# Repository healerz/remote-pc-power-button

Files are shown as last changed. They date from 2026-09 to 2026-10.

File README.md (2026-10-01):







# Remote PC Power Button

A wireless power button for a PC. A button on the desk switches the PC on and off, and its LED shows whether the PC is running. Inside the PC, a second unit closes the motherboard's power switch and senses the PC's power. The two units talk directly over ESP-NOW, so the button works without Home Assistant, the router or the PC's operating system; Home Assistant shows the PC's state and can control it, but is never in the path.

- [Overview](#overview)
- [How it works](#how-it-works)
- [Parts](#parts)
- [Build](#build)
- [Usage](#usage)
- [Known issues](#known-issues)
- [Previews](#previews)
- [Contributing](#contributing)
- [License](#license)
- [Contact](#contact)
- [Disclaimer](#disclaimer)

## Overview

- **Two units**, each an [Arduino Nano ESP32](https://docs.arduino.cc/hardware/nano-esp32/) running [ESPHome](https://esphome.io/): `pc-button-desk` on the desk, with the button; `pc-button-relay` inside the PC, with a relay across the power switch header.
- **The PC case's own power button keeps working**: the relay is wired in parallel to it.
- **Powered from 5 V standby**: the relay unit runs from a motherboard USB header that stays powered while the PC is off, which is exactly when the button is needed.
- **Printable cases** for both units, as `.3mf` with the print settings used, and as `.stl`.
- **Firmware** as one standalone ESPHome configuration per unit.

## How it works

```mermaid
flowchart LR
  HA["Home Assistant"]
  subgraph desk["On the desk"]
    BTN["Kolink button<br>switch and LED"]
    DESK["pc-button-desk<br>Nano ESP32"]
  end
  subgraph pc["PC"]
    RELAY["pc-button-relay<br>Nano ESP32"]
    USB["USB header<br>5VSB"]
    SATA["PSU<br>SATA 5 V"]
    PWR["motherboard<br>PWR_SW header"]
    CASE["case power button"]
  end
  HA <-. "WiFi, native API" .-> DESK
  BTN <-- "switch D2, LED D3" --> DESK
  DESK <-. "ESP-NOW" .-> RELAY
  USB -- "power, also while off" --> RELAY
  SATA -- "sense, via divider" --> RELAY
  RELAY -- "relay NO/COM" --> PWR
  CASE -- "in parallel" --> PWR

  classDef device fill:#e3f2fd,stroke:#1565c0,color:#0d47a1
  classDef part fill:#e8f5e9,stroke:#2e7d32,color:#1b5e20
  classDef module fill:#f3e5f5,stroke:#7b1fa2,color:#4a148c
  classDef connector fill:#e0f7fa,stroke:#00838f,color:#006064
  classDef external fill:#fff3e0,stroke:#ef6c00,color:#e65100
  classDef host fill:#eceff1,stroke:#546e7a,color:#263238
  classDef power fill:#ffebee,stroke:#c62828,color:#b71c1c
  classDef area fill:#fafafa,stroke:#bdbdbd,color:#424242
  classDef pin fill:#ffffff,stroke:#9e9e9e,color:#212121
  classDef passive fill:#ffffff,stroke:#616161,color:#212121
  class DESK,RELAY device
  class BTN,CASE part
  class HA external
  class PWR host
  class USB,SATA power
  class desk,pc area
```

A button press, from the desk to the PC and back:

```mermaid
%%{init: {"theme": "base", "themeCSS": ".actor[name^=device_]{fill:#e3f2fd!important;stroke:#1565c0!important}.actor[name^=device_]+text tspan{fill:#0d47a1!important}.actor[name^=part_]{fill:#e8f5e9!important;stroke:#2e7d32!important}.actor[name^=part_]+text tspan{fill:#1b5e20!important}.actor[name^=module_]{fill:#f3e5f5!important;stroke:#7b1fa2!important}.actor[name^=module_]+text tspan{fill:#4a148c!important}.actor[name^=connector_]{fill:#e0f7fa!important;stroke:#00838f!important}.actor[name^=connector_]+text tspan{fill:#006064!important}.actor[name^=external_]{fill:#fff3e0!important;stroke:#ef6c00!important}.actor[name^=external_]+text tspan{fill:#e65100!important}.actor[name^=host_]{fill:#eceff1!important;stroke:#546e7a!important}.actor[name^=host_]+text tspan{fill:#263238!important}.actor[name^=power_]{fill:#ffebee!important;stroke:#c62828!important}.actor[name^=power_]+text tspan{fill:#b71c1c!important}", "themeVariables": {"actorBkg": "#ffffff", "actorBorder": "#757575", "actorTextColor": "#212121", "actorLineColor": "#9e9e9e", "signalColor": "#212121", "signalTextColor": "#212121", "noteBkgColor": "#ffffff", "noteBorderColor": "#9e9e9e", "noteTextColor": "#212121", "labelBoxBkgColor": "#ffffff", "labelBoxBorderColor": "#212121", "labelTextColor": "#212121", "loopTextColor": "#212121"}}}%%
sequenceDiagram
  box rgb(250,250,250) On the desk
    participant part_button as Kolink button
    participant device_desk as pc-button-desk
  end
  box rgb(250,250,250) PC
    participant device_relay as pc-button-relay
    participant host_board as motherboard
  end
  participant external_ha as Home Assistant
  part_button->>device_desk: pressed
  device_desk->>device_relay: down
  loop every 50 ms while pressed
    device_desk->>device_relay: held
    device_relay->>host_board: relay closed across PWR_SW
  end
  part_button->>device_desk: released
  device_desk->>device_relay: up
  device_relay->>host_board: relay opens 300 ms after the last held
  host_board-->>device_relay: SATA 5 V comes on, D3 high
  device_relay->>device_desk: on, then every second
  device_desk->>external_ha: PC Power on
  device_desk->>part_button: LED on
```

- **The press is repeated, not sent once.** While the button is held, the desk unit sends `held` every 50 ms; the relay unit keeps the relay closed while these arrive and opens it 300 ms after the last one. A lost frame changes nothing, and the relay can never stick closed: an ATX board forces the PC off after about 4 s of a held power switch.
- **The PC's state is repeated too.** The relay unit reports `on` every 1 s while the PC is on, so the LED and Home Assistant heal from a lost frame by themselves.
- **The relay unit keeps its WiFi off.** Inside a PC case the WiFi signal is often weak, and a weak WiFi connection keeps scanning for a better access point. WiFi and ESP-NOW share one radio, so every scan takes it off the ESP-NOW channel for seconds: short taps got through, held presses did not. So the relay unit runs on ESP-NOW alone, and switches WiFi on only for updates, through the Satellite WiFi switch in Home Assistant.
- **It finds its way back by itself.** The relay unit remembers the WiFi channel of its last WiFi session and uses it for ESP-NOW. If the link is lost for about 5 minutes, for example because the router changed its channel, it switches WiFi on, learns the new channel, and returns to ESP-NOW on its own. No channel is configured anywhere.

## Parts

**Parts**

| Part | Qty | For | Details |
|---|---|---|---|
| Solder wire | 1 | project | electronics solder wire; for both units |
| [Double-sided tape](https://www.3m.com/3M/en_US/vhb-tapes-us/) | 1 | project | 3M; VHB acrylic foam tape, 5 m roll; mounts both units, the desk unit under the desk and the relay unit inside the PC case |
| [Arduino Nano ESP32 with headers](https://docs.arduino.cc/hardware/nano-esp32/) | 2 | pc-button-desk ×1, pc-button-relay ×1 | Arduino; pc-button-desk: the headers keep every pin reachable in the case, for jumper wires; pc-button-relay: the headers keep every pin reachable in the case, for jumper wires |
| External power button with cable | 1 | pc-button-desk | Kolink KL-EXPWR; push button with a blue LED, 1.65 m cable; not on the maker's website |
| Resistor, 200 Ω | 1 | pc-button-desk | 200 Ω; LED series resistor, in the patch cable between D3 (GPIO6) and the button's blue LED; limits the current to a few mA, so PWM sets the brightness |
| Jumper wires | 2 | pc-button-desk ×1, pc-button-relay ×1 | Dupont jumper wires, one set |
| USB-C cable | 1 | pc-button-desk | USB-C, to the charger, with a slim plug; a thick plug may not fit the opening of the case |
| USB charger | 1 | pc-button-desk | USB power supply, 5 V |
| Heat-set insert | 14 | pc-button-desk ×5, pc-button-relay ×9 | M3, brass |
| Screw | 14 | pc-button-desk ×5, pc-button-relay ×9 | M3 × 4 mm; pc-button-desk: 4 for the lid, 1 for the clamp that holds the board; pc-button-relay: 4 for the lid, 1 for the clamp that holds the board, 4 for the relay module |
| Heat-shrink tubing | 6 | pc-button-desk ×1, pc-button-relay ×5 | one piece per joint; pc-button-desk: over the joint where the LED resistor is soldered; pc-button-relay: 1 on the SATA power cable; 2 on the Y-split inside the case (power and ground to both the board and the relay module); 2 on the Y-split outside the case at the power switch header, so the PC case's own power button keeps working next to the relay |
| Case | 1 | pc-button-desk | printed: [pc-button-desk-case.3mf](models/pc-button-desk-case.3mf) |
| 1-channel relay module | 1 | pc-button-relay | Purecrea; 5 V, SRD-05VDC-SL-C relay, optocoupler input; trigger jumper on high level, contacts NO and COM used (see the README); the maker has no product page |
| JST XH connector, 5 pins | 1 | pc-button-relay | 2.5 mm pitch, socket in the case and plug on the harness, with crimp contacts; the harness connects the case to the custom-made cable (see photos 02 and 03) |
| SATA power cable | 1 | pc-button-relay | a spare SATA power cable of the PSU, modified; cut down to the 2 wires needed; the other wires cut and sealed with hot glue at the connector |
| Resistor, 10 kΩ | 1 | pc-button-relay | 10 kΩ; PSU sense divider, high side, soldered inline on the SATA power cable from its 5 V wire to the junction |
| Resistor, 20 kΩ | 1 | pc-button-relay | 20 kΩ; PSU sense divider, low side, from the junction to the spliced ground wire; the junction goes to D3 (GPIO6) at 5 V × 20/30 = 3.33 V, low enough in value to dominate the pin's 45 kΩ internal pull-down |
| Hot glue | 1 | pc-button-relay | glue sticks for the hot glue gun; seals the cut wires of the SATA power cable |
| Super glue | 1 | pc-button-relay | cyanoacrylate glue; holds the JST XH socket in the case, which has no stop against pulling it out |
| Case | 1 | pc-button-relay | printed: [pc-button-relay-case.3mf](models/pc-button-relay-case.3mf) |

**Tools**

| Tool | For | Details |
|---|---|---|
| 3D printer | project | for both cases |
| Soldering iron | project | for the wires, and to set the heat-set inserts |
| Wire stripper | project |  |
| [Soldering tips for heat-set inserts](https://www.ruthex.de/en/products/ruthex-lotspitzen-einschmelzhilfe-m2-m2-5-m3-m4-m5-m6-m8) (optional) | project | ruthex LOE-SET-012; set the inserts straight |
| Heat gun (optional) | project | to shrink the heat-shrink tubing; a soldering iron works too |
| Multimeter (optional) | project | to check the sense divider, about 3.0 V at the relay unit's D3 with the PC on and 0 V with it off |
| JST XH crimping tool | pc-button-relay |  |
| Hot glue gun | pc-button-relay | to seal the cut wires of the SATA power cable |

**Requires**

- A motherboard USB header that stays powered while the PC is off: 5VSB; the relay unit lives on it. The BIOS must keep it powered in the off state (ErP disabled, or USB power in S5 enabled), or the button does nothing while the PC is off
- A spare SATA power cable of this PSU, or a free SATA plug: for the relay unit's modified SATA power cable, which senses whether the PC is on. Modular PSU cables are specific to their PSU on the PSU end; a cable from another PSU can destroy hardware

## Build

### Printing

| Part | Files | Printer | Profile | Filament | Layer height | Infill | Walls | Supports |
|---|---|---|---|---|---|---|---|---|
| `pc-button-desk` case | [3mf](models/pc-button-desk-case.3mf), [stl](models/pc-button-desk-case.stl) | Bambu Lab X1 Carbon 0.4 nozzle | ESP_desk - 0.16mm High Quality @BBL X1C | Bambu PETG HF @BBL X1C | 0.16 mm | 20% | 4 | none |
| `pc-button-relay` case | [3mf](models/pc-button-relay-case.3mf), [stl](models/pc-button-relay-case.stl) | Bambu Lab X1 Carbon 0.4 nozzle | ESP_desk - 0.16mm High Quality @BBL X1C | Bambu PETG HF @BBL X1C | 0.16 mm | 20% | 4 | none |
| all: pc-remote-power-button-cases | [3mf](models/pc-remote-power-button-cases.3mf) | Bambu Lab X1 Carbon 0.4 nozzle | ESP_desk - 0.16mm High Quality @BBL X1C | Bambu PETG HF @BBL X1C | 0.16 mm | 20% | 4 | none |

Both cases are sized for the Nano ESP32 with headers, so all pins stay reachable for jumper wires. A Nano without headers fits as well; the case is then a bit bigger than needed.

Print both cases lying flat, in PETG. A case printed standing on its end broke under finger pressure: every wall then consists of layer boundaries.

### Wiring

#### Desk unit

The button's own leads go straight onto the board's header pins: the switch pair on D2 and the GND next to it, the LED through a 200 Ω resistor on D3 and back to the other GND.

```mermaid
%%{init: {"flowchart": {"subGraphTitleMargin": {"top": 0, "bottom": 8}, "rankSpacing": 60, "nodeSpacing": 55, "curve": "linear"}}}%%
flowchart LR
  subgraph CHARGER["USB charger, 5 V"]
    direction TB
    CHARGER_0["USB-C"]
  end
  subgraph CASE["Case"]
    direction LR
    subgraph NANO["Arduino Nano ESP32"]
      direction TB
      NANO_0["USB-C"]
      NANO_1["D2 (GPIO5)"]
      NANO_2["GND (by D2)"]
      NANO_3["GND (by VIN)"]
      NANO_4["D3 (GPIO6)"]
    end
    R3["200 Ω"]
  end
  subgraph BUTTON["Kolink power button"]
    direction TB
    BUTTON_0["SW A"]
    BUTTON_1["SW B"]
    BUTTON_2["LED-"]
    BUTTON_3["LED+"]
  end
  CHARGER_0 --- NANO_0
  NANO_1 --- BUTTON_0
  NANO_2 --- BUTTON_1
  NANO_3 --- BUTTON_2
  NANO_4 --- R3
  R3 --- BUTTON_3
  linkStyle 0 stroke:#212121,stroke-width:4px,marker-end:none
  linkStyle 1 stroke:#e0e0e0,stroke-width:4px,marker-end:none
  linkStyle 2 stroke:#00897b,stroke-width:4px,marker-end:none
  linkStyle 3 stroke:#212121,stroke-width:4px,marker-end:none
  linkStyle 4 stroke:#d32f2f,stroke-width:4px,marker-end:none
  linkStyle 5 stroke:#d32f2f,stroke-width:4px,marker-end:none

  classDef device fill:#e3f2fd,stroke:#1565c0,color:#0d47a1
  classDef part fill:#e8f5e9,stroke:#2e7d32,color:#1b5e20
  classDef module fill:#f3e5f5,stroke:#7b1fa2,color:#4a148c
  classDef connector fill:#e0f7fa,stroke:#00838f,color:#006064
  classDef external fill:#fff3e0,stroke:#ef6c00,color:#e65100
  classDef host fill:#eceff1,stroke:#546e7a,color:#263238
  classDef power fill:#ffebee,stroke:#c62828,color:#b71c1c
  classDef area fill:#fafafa,stroke:#bdbdbd,color:#424242
  classDef pin fill:#ffffff,stroke:#9e9e9e,color:#212121
  classDef passive fill:#ffffff,stroke:#616161,color:#212121
  class CHARGER power
  class NANO device
  class R3 passive
  class BUTTON part
  class CASE area
  class CHARGER_0,NANO_0,NANO_1,NANO_2,NANO_3,NANO_4,BUTTON_0,BUTTON_1,BUTTON_2,BUTTON_3 pin
```

#### Relay unit

The relay unit connects to the PC through one 5-pin JST XH connector in its case wall: 5VSB and GND from a motherboard USB header, the sense line, and the power switch pair.

```mermaid
%%{init: {"flowchart": {"subGraphTitleMargin": {"top": 0, "bottom": 8}, "rankSpacing": 60, "nodeSpacing": 55, "curve": "linear"}}}%%
flowchart LR
  subgraph SATA["SATA plug of the PSU"]
    direction TB
    SATA_0["+5V"]
    SATA_1["GND"]
  end
  R1["10 kΩ"]
  J(("Y-split"))
  R2["20 kΩ"]
  subgraph USB["USB header, 5VSB"]
    direction TB
    USB_0["5VSB"]
    USB_1["GND"]
  end
  subgraph PWRSW["PWR_SW header"]
    direction TB
    PWRSW_0["SW A"]
    PWRSW_1["SW B"]
  end
  subgraph BUTTON["PC case button"]
    direction TB
    BUTTON_0["SW A"]
    BUTTON_1["SW B"]
  end
  YA(("Y-split"))
  YB(("Y-split"))
  subgraph CASE["Case"]
    direction LR
    subgraph XH["XH, in the case wall"]
      direction TB
      XH_0["1 5VSB"]
      XH_1["2 GND"]
      XH_2["3 SENSE"]
      XH_3["4 SW A"]
      XH_4["5 SW B"]
    end
    S5V(("Y-split"))
    SGND(("Y-split"))
    subgraph NANO["Arduino Nano ESP32"]
      direction TB
      NANO_0["VBUS"]
      NANO_1["GND"]
      NANO_2["D2 (GPIO5)"]
      NANO_3["D3 (GPIO6)"]
    end
    subgraph RELAY["relay module"]
      direction TB
      RELAY_0["VCC"]
      RELAY_1["GND"]
      RELAY_2["COM"]
      RELAY_3["NO"]
      RELAY_4["IN"]
    end
  end
  SATA_0 --- R1
  R1 --- J
  SATA_1 --- R2
  R2 --- J
  J --- XH_2
  USB_0 --- XH_0
  USB_1 --- XH_1
  PWRSW_0 --- YA
  BUTTON_0 --- YA
  YA --- XH_3
  PWRSW_1 --- YB
  BUTTON_1 --- YB
  YB --- XH_4
  XH_0 --- S5V
  XH_1 --- SGND
  S5V --- RELAY_0
  SGND --- RELAY_1
  XH_3 --- RELAY_2
  XH_4 --- RELAY_3
  RELAY_4 --- NANO_2
  S5V --- NANO_0
  SGND --- NANO_1
  XH_2 --- NANO_3
  linkStyle 0 stroke:#d32f2f,stroke-width:4px,marker-end:none
  linkStyle 1 stroke:#7b1fa2,stroke-width:4px,marker-end:none
  linkStyle 2 stroke:#212121,stroke-width:4px,marker-end:none
  linkStyle 3 stroke:#7b1fa2,stroke-width:4px,marker-end:none
  linkStyle 4 stroke:#7b1fa2,stroke-width:4px,marker-end:none
  linkStyle 5 stroke:#d32f2f,stroke-width:4px,marker-end:none
  linkStyle 6 stroke:#212121,stroke-width:4px,marker-end:none
  linkStyle 7 stroke:#9e9e9e,stroke-width:4px,marker-end:none
  linkStyle 8 stroke:#9e9e9e,stroke-width:4px,marker-end:none
  linkStyle 9 stroke:#9e9e9e,stroke-width:4px,marker-end:none
  linkStyle 10 stroke:#fbc02d,stroke-width:4px,marker-end:none
  linkStyle 11 stroke:#fbc02d,stroke-width:4px,marker-end:none
  linkStyle 12 stroke:#fbc02d,stroke-width:4px,marker-end:none
  linkStyle 13 stroke:#d32f2f,stroke-width:4px,marker-end:none
  linkStyle 14 stroke:#212121,stroke-width:4px,marker-end:none
  linkStyle 15 stroke:#d32f2f,stroke-width:4px,marker-end:none
  linkStyle 16 stroke:#212121,stroke-width:4px,marker-end:none
  linkStyle 17 stroke:#9e9e9e,stroke-width:4px,marker-end:none
  linkStyle 18 stroke:#fbc02d,stroke-width:4px,marker-end:none
  linkStyle 19 stroke:#7b1fa2,stroke-width:4px,marker-end:none
  linkStyle 20 stroke:#d32f2f,stroke-width:4px,marker-end:none
  linkStyle 21 stroke:#212121,stroke-width:4px,marker-end:none
  linkStyle 22 stroke:#7b1fa2,stroke-width:4px,marker-end:none

  classDef device fill:#e3f2fd,stroke:#1565c0,color:#0d47a1
  classDef part fill:#e8f5e9,stroke:#2e7d32,color:#1b5e20
  classDef module fill:#f3e5f5,stroke:#7b1fa2,color:#4a148c
  classDef connector fill:#e0f7fa,stroke:#00838f,color:#006064
  classDef external fill:#fff3e0,stroke:#ef6c00,color:#e65100
  classDef host fill:#eceff1,stroke:#546e7a,color:#263238
  classDef power fill:#ffebee,stroke:#c62828,color:#b71c1c
  classDef area fill:#fafafa,stroke:#bdbdbd,color:#424242
  classDef pin fill:#ffffff,stroke:#9e9e9e,color:#212121
  classDef passive fill:#ffffff,stroke:#616161,color:#212121
  class SATA,USB power
  class R1,J,R2,YA,YB,S5V,SGND passive
  class PWRSW host
  class BUTTON part
  class XH connector
  class NANO device
  class RELAY module
  class CASE area
  class SATA_0,SATA_1,USB_0,USB_1,PWRSW_0,PWRSW_1,BUTTON_0,BUTTON_1,XH_0,XH_1,XH_2,XH_3,XH_4,NANO_0,NANO_1,NANO_2,NANO_3,RELAY_0,RELAY_1,RELAY_2,RELAY_3,RELAY_4 pin
```

- **Relay module:** set its trigger jumper to high level, and use the contacts NO and COM. On low level, the relay would close during every boot and press the PC's power switch; on NC the switch would be held closed.
- **Power switch:** two Y-splits put the relay in parallel to the PC case's own button, on the motherboard's power switch header.
- **Power sense:** a 10 kΩ / 20 kΩ divider on the 5 V wire of a spare SATA power cable of the PSU gives about 3.3 V at D3 while the PC is on. Use a cable of this PSU only: modular PSU cables are specific to their PSU, and a cable from another PSU can destroy hardware.
- **Power supply:** 5VSB from a USB header that stays powered while the PC is off (BIOS: ErP disabled, or USB power in S5 enabled). VBUS is wired straight to the board's USB-C port, so unplug the harness before connecting a USB-C cable to the board.

### Assembly

- **Both cases:** the Nano ESP32 goes in USB-C end first, and a printed clamp, screwed on at the antenna end, holds it down. All header pins stay reachable, so the wiring plugs on with jumper wires. The lid is held by 4 M3 screws in heat-set inserts.
- **Desk unit:** shaking the case a little seats the board. The opening for the USB-C cable fits a slim plug. The button's cable is held by the pressure of the lid, which also relieves the strain on its leads.
- **Relay unit:** the relay module is held by 4 screws. The XH socket sits in the case wall; the case has a stop against pushing it in but none against pulling it out, so glue it in (cyanoacrylate).
- **Mounting:** double-sided tape holds both units, the desk unit under the desk and the relay unit inside the PC case.

### Flashing

The configurations are in [`esphome/`](esphome/), one standalone file per unit, for the [ESPHome](https://esphome.io/) dashboard, the Home Assistant add-on or the command line. They need ESPHome 2026.9.0 or newer, and Home Assistant: its Satellite WiFi switch is the only way to switch the relay unit's WiFi off after the first flash, and on for updates.

1. **Secrets:** copy [`esphome/secrets.example.yaml`](esphome/secrets.example.yaml) to `secrets.yaml` next to the configurations and fill in your WiFi. Give each unit its own API encryption key, for example from `openssl rand -base64 32`.
2. **First flash, over USB:** flash both units once. Each one logs its MAC address at boot (`Local MAC` in the WiFi section of the log).
3. **MACs:** each unit sends to the other one's MAC. Put the relay unit's MAC into the desk unit's configuration (`pc_button_relay_mac` in its `substitutions`), and the desk unit's MAC into the relay unit's (`pc_button_desk_mac`).
4. **Second flash:** the relay unit first, then the desk unit. Both units have to run the same release: the desk unit repeats its WiFi commands, which an older relay unit would answer by rebooting over and over.
5. **Home Assistant:** add the desk unit through the ESPHome integration, with its API key. The relay unit has no entities and needs no integration.
6. **WiFi off:** a newly flashed relay unit starts with WiFi on, so it can learn the channel. Once it has joined your WiFi, switch Satellite WiFi off in Home Assistant.

## Usage

- **Button:** press it to switch the PC on or off, as with the case's own button. Holding it for about 4 s forces the PC off.
- **LED:** lit while the PC is on.
- **Home Assistant** (desk unit):
  - *PC Power*: whether the PC is on.
  - *Satellite Link*: whether the desk unit hears the relay unit.
  - *Satellite WiFi*: the relay unit's WiFi. Switch it on to update the relay unit over the air, and off afterwards. The switch shows the relay unit's own report, not just the command.
- **Updating the relay unit:** switch Satellite WiFi on, wait until the relay unit is online, flash it, and switch Satellite WiFi off again. WiFi that cannot connect within 5 min switches itself off again.

## Known issues

- Both units must be flashed together, relay unit first: the desk unit's repeated WiFi commands would keep an older relay unit rebooting.
- WiFi reception inside a PC case can be too weak for the relay unit to hold a connection, so an OTA update may need the case opened or several attempts; the button itself does not depend on WiFi.
- While the relay unit is on WiFi, the ESP-NOW link is less reliable: WiFi scans take the shared radio off the channel.
- ESP-NOW frames are not authenticated: the units only accept frames from each other's MAC address, which a sender in radio range could imitate.
- Recovering the desk unit from a broken configuration needs USB, since it has no fallback access point.

## Previews

### Desk unit

The printed case body with threaded inserts, the lid and the small plate

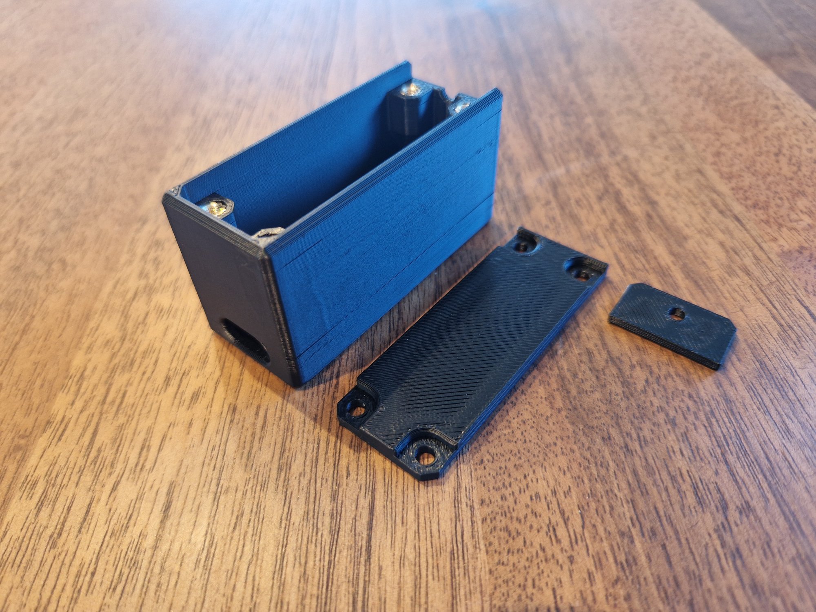
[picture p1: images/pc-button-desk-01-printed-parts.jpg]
the printed case body with threaded inserts, the lid and the small plate


The Nano ESP32 in the open case, wired to the button cable

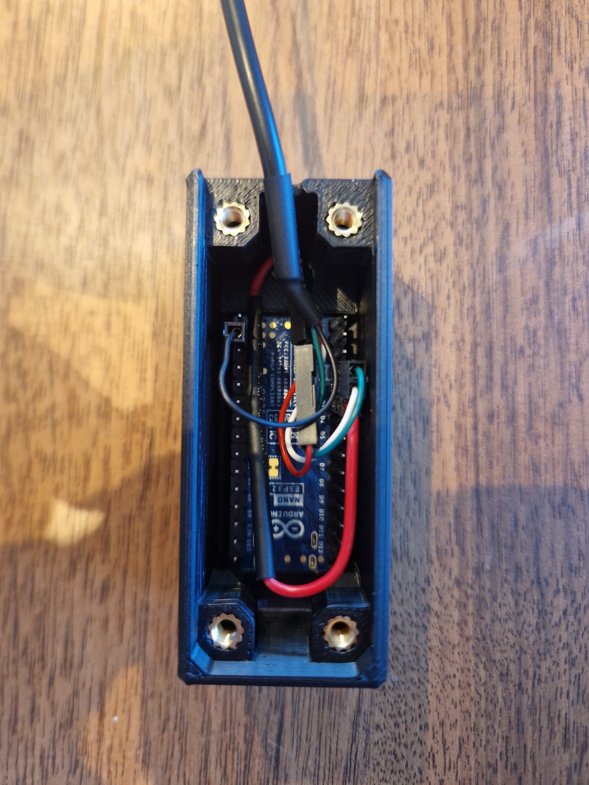
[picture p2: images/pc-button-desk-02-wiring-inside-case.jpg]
the Nano ESP32 in the open case, wired to the button cable


The closed case next to the key-switch power button

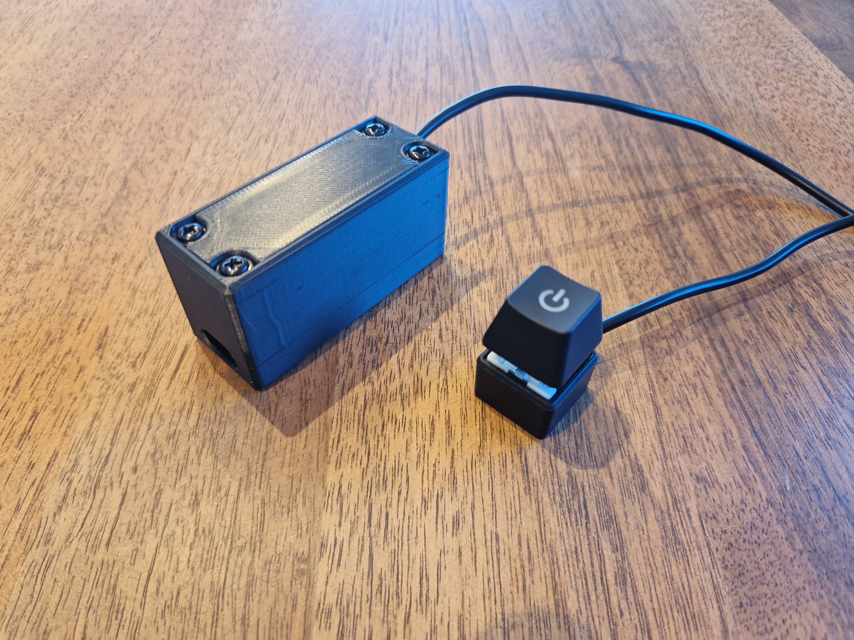
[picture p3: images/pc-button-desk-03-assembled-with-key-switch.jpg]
the closed case next to the key-switch power button


Mounted under the desk, the button lit blue while the PC is on

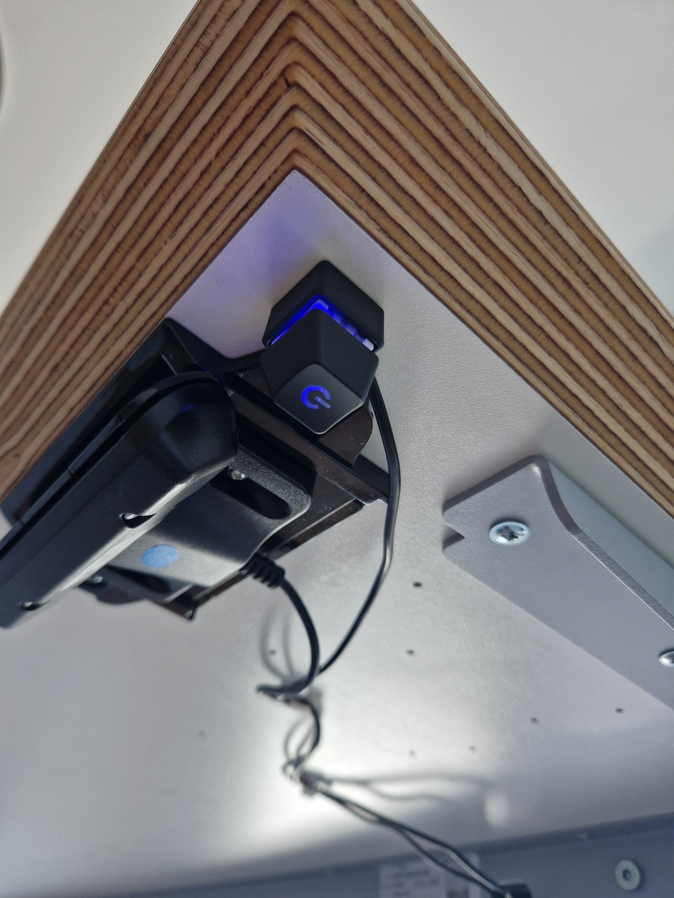
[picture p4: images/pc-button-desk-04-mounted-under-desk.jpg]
mounted under the desk, the button lit blue while the PC is on


Section view of the case design in Fusion: the lid, the screw channels and the slot for the board

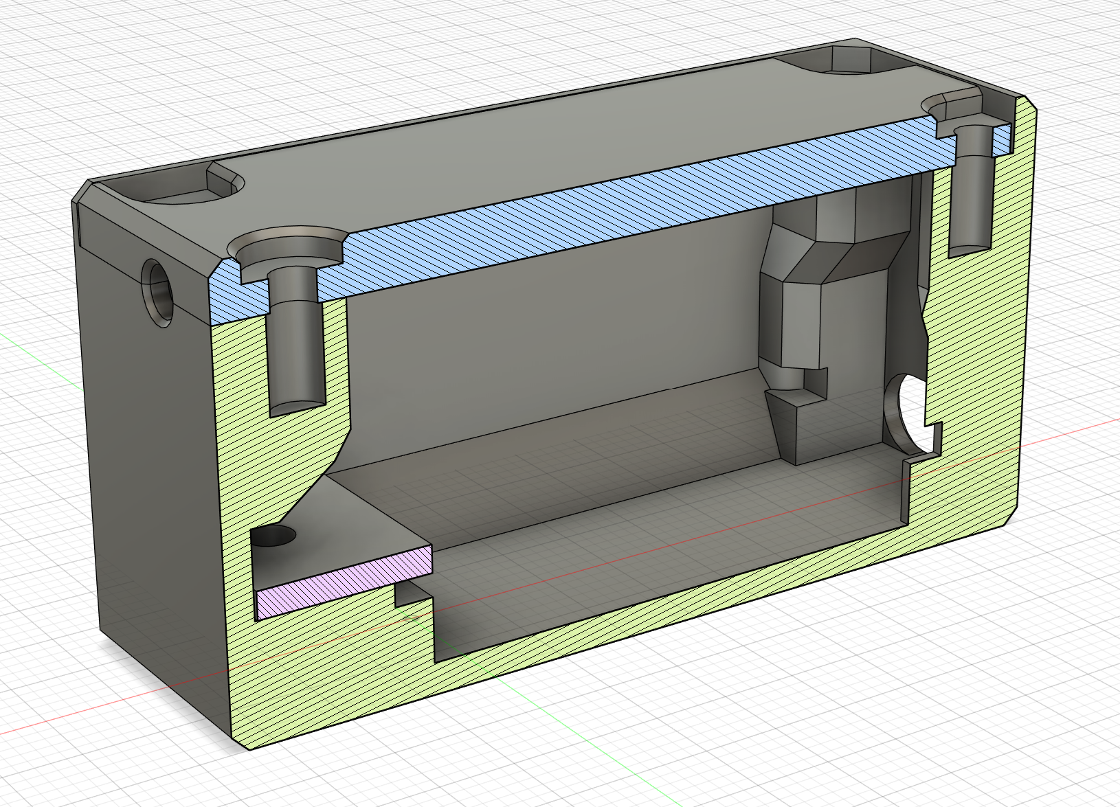
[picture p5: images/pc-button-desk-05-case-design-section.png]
section view of the case design in Fusion: the lid, the screw channels and the slot for the board


### Relay unit

The printed case body with threaded inserts, the lid and the small plate

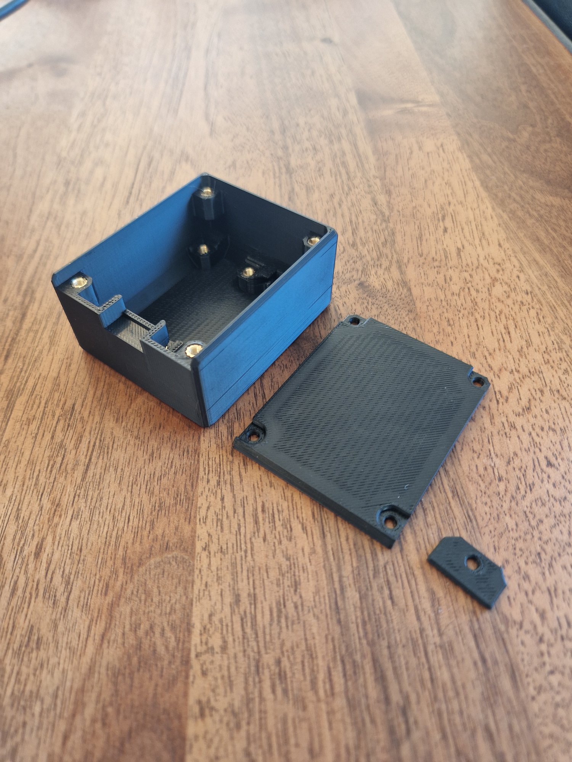
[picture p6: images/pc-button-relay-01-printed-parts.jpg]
the printed case body with threaded inserts, the lid and the small plate


The relay module, the Nano ESP32 and the 5-pin connector in the open case

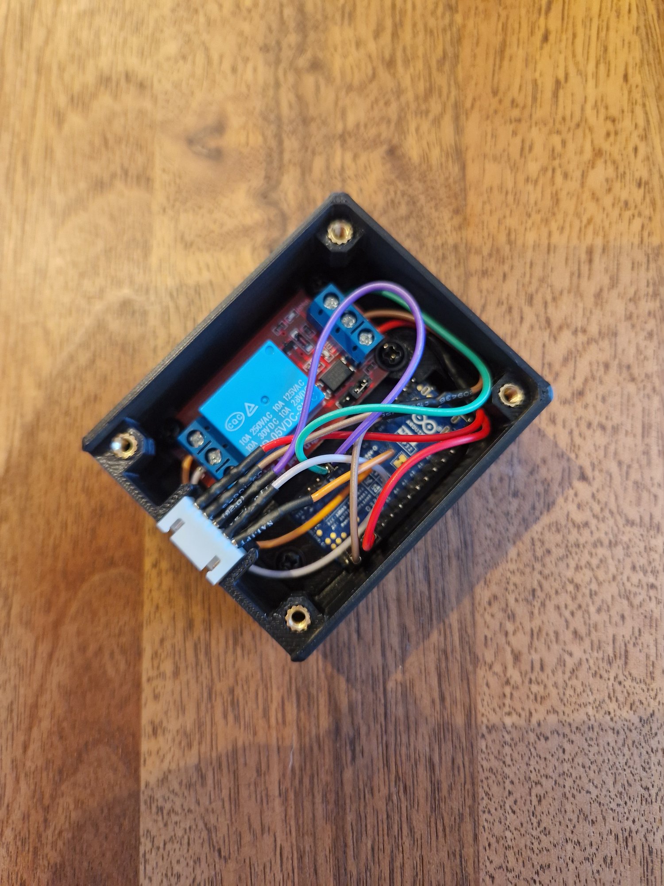
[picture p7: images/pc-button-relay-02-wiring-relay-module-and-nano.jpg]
the relay module, the Nano ESP32 and the 5-pin connector in the open case


The closed case with the 5-pin harness to the motherboard headers

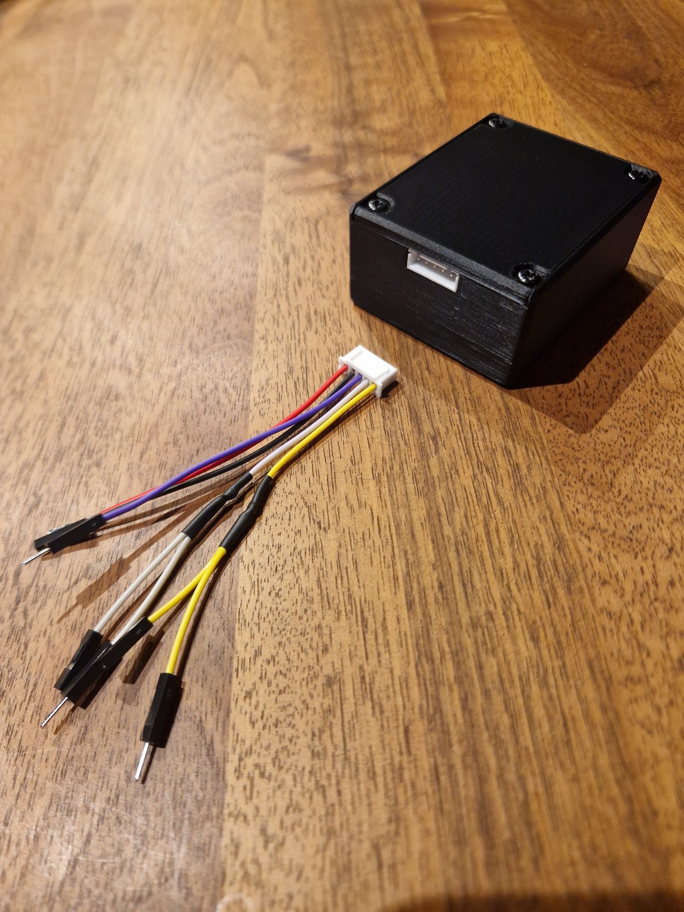
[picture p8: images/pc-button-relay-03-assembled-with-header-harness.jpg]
the closed case with the 5-pin harness to the motherboard headers


Installed inside the PC case, below the graphics card

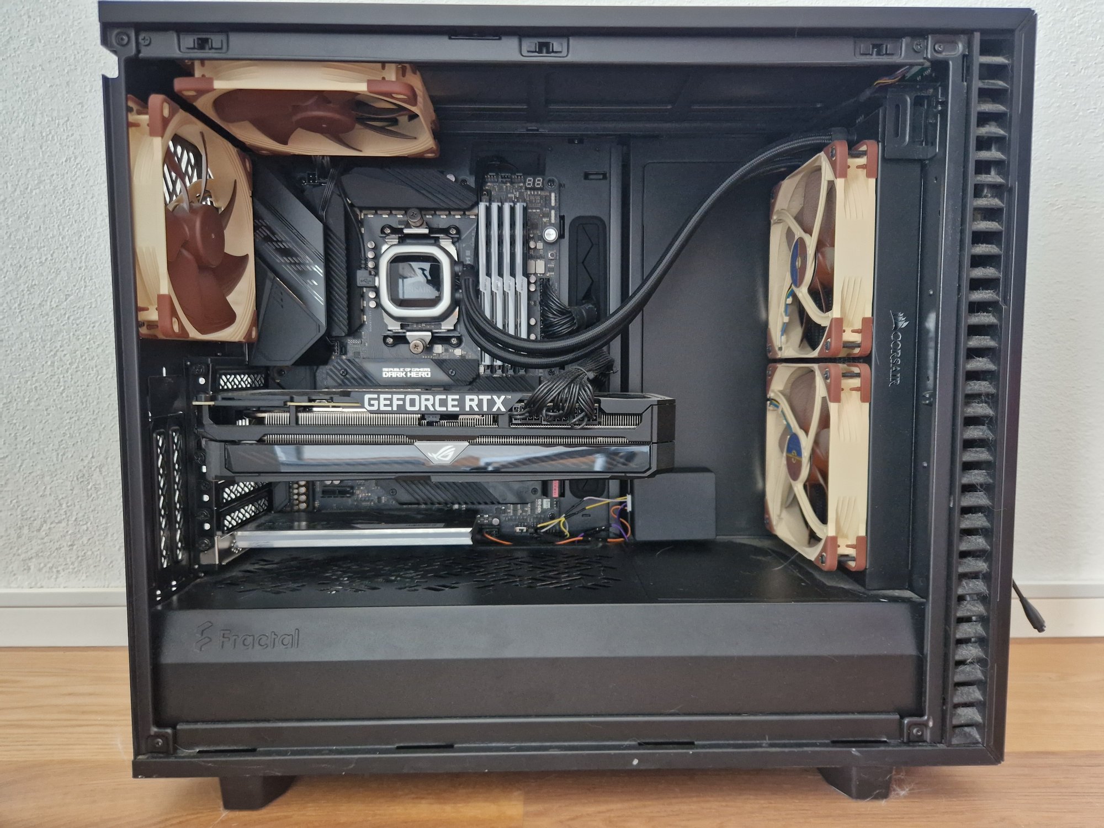
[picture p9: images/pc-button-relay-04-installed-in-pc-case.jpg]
installed inside the PC case, below the graphics card


Section view of the case design in Fusion: the lid and the mounts for the relay module and the board

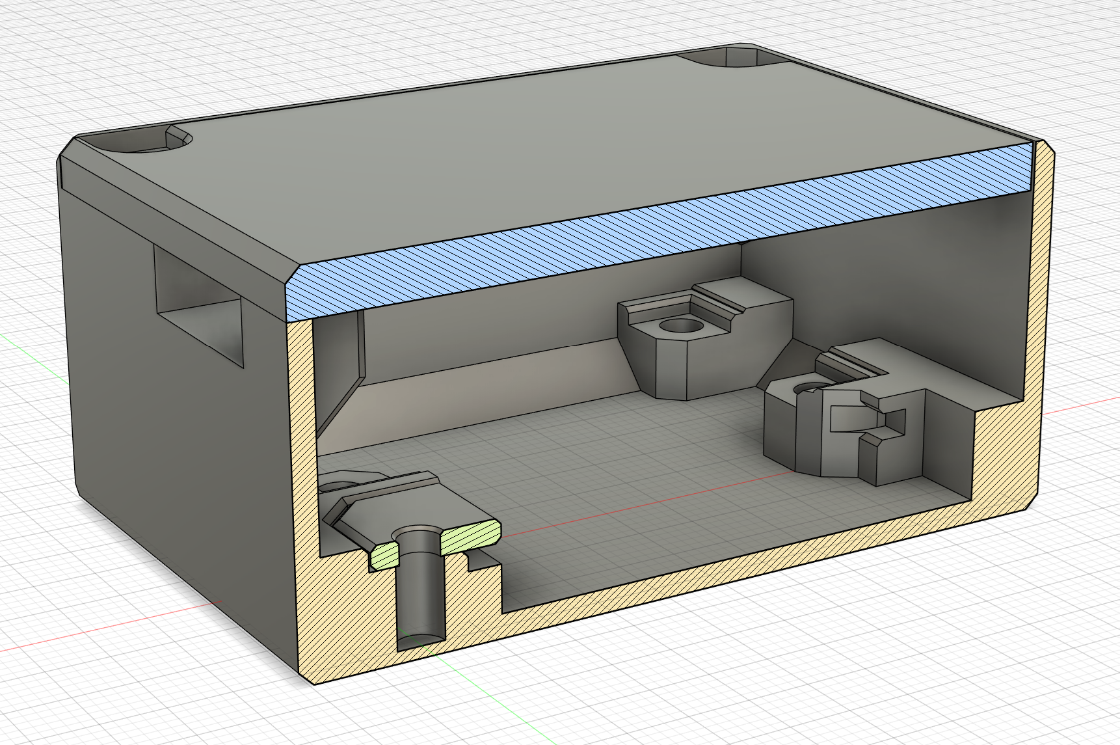
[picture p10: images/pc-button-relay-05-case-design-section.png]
section view of the case design in Fusion: the lid and the mounts for the relay module and the board


## Contributing

Contributions are welcome! You can help by:
- Suggesting improvements to the design or the firmware
- Testing it with other boards, cases or PCs, and sharing the results
- Improving the documentation

To contribute, open an issue or a pull request.

## License

This project is licensed under the [Creative Commons Attribution-NonCommercial-ShareAlike 4.0 International (CC BY-NC-SA 4.0)](https://creativecommons.org/licenses/by-nc-sa/4.0/) license, the configurations included.

You are free to:
- Share: copy and redistribute the material in any medium or format
- Adapt: remix, transform, and build upon the material

Under the following terms:
- Attribution: you must credit the creator.
- NonCommercial: you may not use the material for commercial purposes.
- ShareAlike: you must distribute your contributions under the same license.

## Contact

Questions, feedback, or suggestions? Open an [issue](../../issues).

## Disclaimer

This project is not affiliated with Kolink, Arduino, Espressif, ESPHome or Home Assistant. Working inside a PC and modifying PSU cables is at your own risk: disconnect the PC from mains power before opening it, and check the wiring before powering it again.

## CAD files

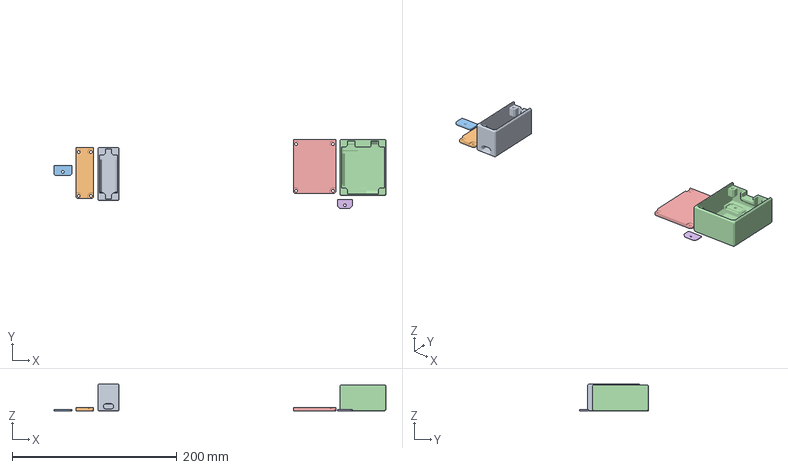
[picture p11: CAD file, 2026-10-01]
models/pc-remote-power-button-cases.3mf
403.1 x 83.8 x 32.6 mm

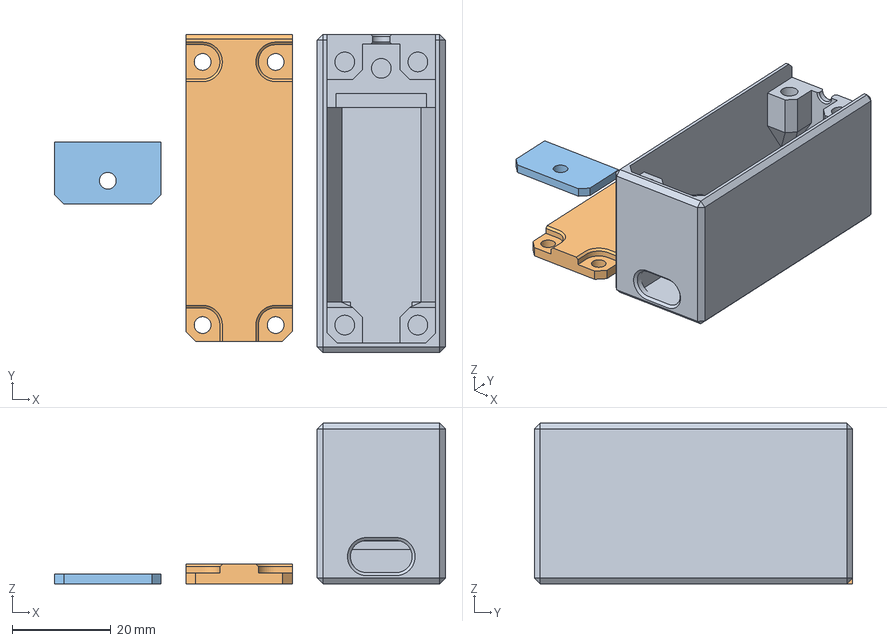
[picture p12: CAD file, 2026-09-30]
models/pc-button-desk-case.3mf
79.2 x 64.5 x 32.6 mm

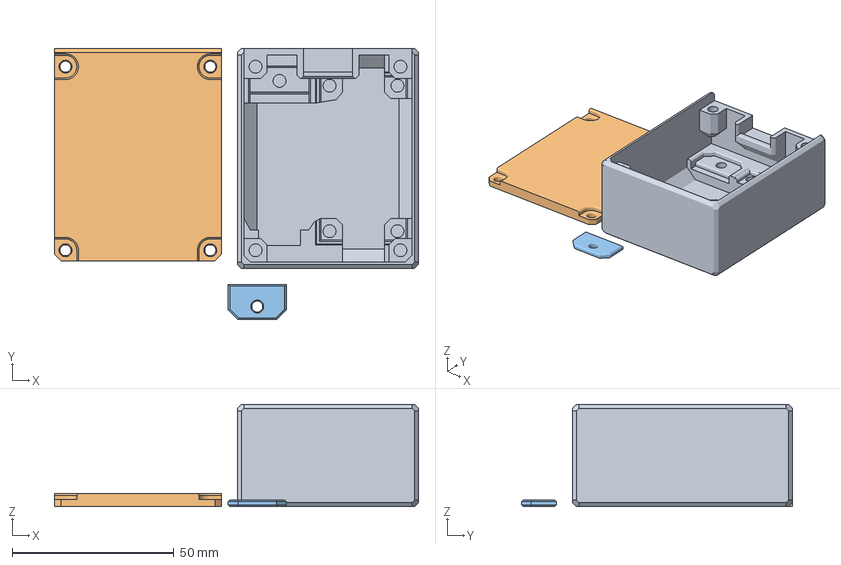
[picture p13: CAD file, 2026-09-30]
models/pc-button-relay-case.3mf
112.6 x 83.8 x 31.6 mm

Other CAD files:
models/pc-button-desk-case.stl
models/pc-button-relay-case.stl

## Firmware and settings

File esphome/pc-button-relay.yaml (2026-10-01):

# remote-pc-power-button v2.0.4: pc-button-relay. See the README for the secrets and the MACs to fill in.

# Board: Arduino Nano ESP32, inside the PC; remote I/O of pc-button-desk
# Actuator: relay on PWR_SW header | Sensor: PSU 5V divider
# Powered from USB header 5VSB, alive while the PC is off; do not move to a switched rail.
#
# WiFi is off by default so the radio never leaves the AP's channel to scan.
# Turn it on via the desk unit's "Satellite WiFi" switch when OTA is needed.
# Rescue: rescue_failures consecutive failed reports while WiFi is off → enable WiFi and reboot.
# ESP-NOW with WiFi off uses the channel of the last WiFi session, saved on
# connect. Until a channel has been saved (a new board), it always starts with
# WiFi on: without a known channel ESP-NOW cannot work, so there is no guessing.
# A router channel change heals itself: the rescue brings WiFi back on the new
# channel, and after rescue_return_reports reports delivered on WiFi the unit switches WiFi off
# again and carries the saved channel over to ESP-NOW. Only a rescue returns
# by itself; WiFi switched on by wifi_on stays on until wifi_off, unless it has
# not connected wifi_connect_timeout after boot: then the unit returns to WiFi off.
#
# No fallback access point and no captive portal: they would contradict WiFi
# being off by default.

substitutions:
  name: pc-button-relay
  project: remote-pc-power-button
  pc_button_desk_mac: "02:00:00:00:00:21"  # MAC of that unit, from its boot log (see the README)
  held_timeout: 300ms # relay unit opens the relay this long after the last held
  state_interval: 1s # relay unit repeats on this often while the PC is on
  report_interval: 30s # relay unit reports its WiFi state this often
  rescue_failures: "10"        # failed reports in a row, with WiFi off, before the rescue: 5 min at report_interval
  rescue_return_reports: "3"   # reports delivered on WiFi after a rescue before WiFi goes off again
  wifi_connect_timeout: 5min   # WiFi that has not connected this long after boot falls back to off
  sense_debounce: 100ms        # the PC power sense must hold its new level this long to count

esphome:
  project:
    name: ${project}.${name}
    version: v2.0.4
  name: ${name}
  friendly_name: PC Button Relay
  on_boot:
    - priority: 250                 # after logger and core components
      then:
        - lambda: |-
            ESP_LOGI("sat", "boot: boot_wifi_enabled=%s",
                     id(boot_wifi_enabled) ? "true" : "false");
        - if:
            condition:
              lambda: 'return id(boot_wifi_enabled) || id(espnow_channel) == 0;'
            then:
              - lambda: |-
                  ESP_LOGI("sat", "boot: enabling wifi%s",
                           id(espnow_channel) == 0 ? " (no espnow channel saved yet)" : "");
              - wifi.enable:
              - script.execute: wifi_connect_watchdog
            else:
              - espnow.set_channel: !lambda 'return id(espnow_channel);'
              - lambda: 'ESP_LOGI("sat", "boot: wifi stays off, channel set to %u", id(espnow_channel));'
    - priority: -100                # after everything is up
      then:
        - script.execute: report_wifi_state

esp32:
  variant: esp32s3
  flash_size: 16MB
  framework:
    type: esp-idf

globals:
  - id: boot_wifi_enabled
    type: bool
    restore_value: true
    initial_value: 'true'           # fresh flash comes up reachable

  - id: espnow_channel              # channel of the last WiFi session
    type: uint8_t
    restore_value: true
    initial_value: '0'              # 0: none saved yet, so WiFi starts on

  - id: wifi_by_rescue              # WiFi is on because of a rescue, not wifi_on
    type: bool
    restore_value: true
    initial_value: 'false'

  - id: rescue_reports              # reports delivered on WiFi since a rescue
    type: int
    restore_value: false
    initial_value: '0'

  - id: rescue_return               # reports it takes to switch WiFi off again
    type: int
    restore_value: false
    initial_value: '${rescue_return_reports}'

  - id: send_failures               # consecutive failed reports
    type: int
    restore_value: false
    initial_value: '0'

  - id: fail_threshold              # rescue_failures reports at report_interval
    type: int
    restore_value: false
    initial_value: '${rescue_failures}'

api:                                # kept for OTA/logs only — no entities
  encryption:
    key: !secret pc_button_relay_api_key
  reboot_timeout: 0s                # relay unit runs HA-less by design


ota:
  - platform: esphome
    encryption:                     # inherits the api key

safe_mode:                          # after repeated failed boots: WiFi on, so an OTA update can recover it
  on_safe_mode:
    - wifi.enable:
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

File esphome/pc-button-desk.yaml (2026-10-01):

# remote-pc-power-button v2.0.4: pc-button-desk. See the README for the secrets and the MACs to fill in.

# Desk unit: the physical power button and status LED, on WiFi and in Home
# Assistant. Talks to pc-button-relay inside the PC over ESP-NOW.
# Board: Arduino Nano ESP32.
#
# No fallback access point: it would open on a channel of its
# own when the router is away, and take the radio off the ESP-NOW channel the
# relay unit uses; the button would stop working exactly when it should not
# depend on the router. Recovery is over USB, next to the desk.

substitutions:
  name: pc-button-desk
  project: remote-pc-power-button
  pc_button_relay_mac: "02:00:00:00:00:22"  # MAC of that unit, from its boot log (see the README)
  held_interval: 50ms # desk unit repeats held this often while the button is pressed
  led_timeout: 4s # desk unit takes the PC as off after this long without on
  link_timeout: 90s # desk unit takes the link as lost after this long without any frame
  wifi_request_interval: 1s    # a WiFi request is repeated this often until the relay unit reports it
  wifi_request_limit: "300"    # requests before giving up: 5 min at one per second

esphome:
  project:
    name: ${project}.${name}
    version: v2.0.4
  name: ${name}
  friendly_name: PC Button Desk
  on_boot:
    - script.execute: led_state_watchdog

esp32:
  variant: esp32s3
  flash_size: 16MB
  framework:
    type: esp-idf

globals:
  - id: wifi_request              # relay unit WiFi asked for: 0 none, 1 on, 2 off
    type: int
    restore_value: false
    initial_value: '0'

  - id: wifi_request_sends        # repeats of the current request
    type: int
    restore_value: false
    initial_value: '0'

  - id: sat_wifi_known            # relay unit WiFi as last reported: -1 unknown, 0 off, 1 on
    type: int
    restore_value: false
    initial_value: '-1'

logger:
  logs:
    script: INFO                    # the two watchdogs re-arm every second

api:
  encryption:
    key: !secret pc_button_desk_api_key
  reboot_timeout: 0s                # the button works without Home Assistant: no reboot when it is away

ota:
  - platform: esphome
    encryption:                     # inherits the api key

safe_mode:                          # after repeated failed boots, wait for an OTA update

wifi:
  ssid: !secret wifi_ssid
  password: !secret wifi_password
  power_save_mode: none
  reboot_timeout: 0s                # nor when the router is away

# ── ESP-NOW link to the relay unit ─────────────────────────────
# → down / held / up / wifi_on / wifi_off
# ← on / off                             (PC power)
# ← sat_wifi_enabled / sat_wifi_disabled (relay unit WiFi component state)
espnow:
  peers:
    - ${pc_button_relay_mac}
  on_receive:
    - lambda: 'id(sat_link).publish_state(true);'   # any frame proves the link
    - script.execute: link_watchdog
    - if:
        condition:
          lambda: 'return size == 2 && memcmp(data, "on", 2) == 0;'
        then:
          - light.turn_on:
              id: status_led
              brightness: 60%
          - binary_sensor.template.publish:
              id: pc_power_remote
              state: ON
          - script.execute: led_state_watchdog
    - if:
        condition:
          lambda: 'return size == 3 && memcmp(data, "off", 3) == 0;'
        then:
          - script.stop: led_state_watchdog
          - light.turn_off: status_led
          - binary_sensor.template.publish:
              id: pc_power_remote
              state: OFF
    - if:
        condition:
          lambda: 'return size == 16 && memcmp(data, "sat_wifi_enabled", 16) == 0;'
        then:
          - lambda: |-
              id(sat_wifi_sw).publish_state(true);
              if (id(sat_wifi_known) == 0 && id(wifi_request) != 1)   // a rescue
                ESP_LOGW("sat", "relay unit switched its WiFi on by itself");
              id(sat_wifi_known) = 1;
              if (id(wifi_request) == 1) id(wifi_request) = 0;   // confirmed
    - if:
        condition:
          lambda: 'return size == 17 && memcmp(data, "sat_wifi_disabled", 17) == 0;'
        then:
          - lambda: |-
              id(sat_wifi_sw).publish_state(false);
              if (id(sat_wifi_known) == 1 && id(wifi_request) != 2)   // back after a rescue, or a fallback
                ESP_LOGW("sat", "relay unit switched its WiFi off by itself");
              id(sat_wifi_known) = 0;
              if (id(wifi_request) == 2) id(wifi_request) = 0;   // confirmed
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

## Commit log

2026-09-30 remote-pc-power-button v2.0.1
    [pc-button-desk-case.3mf, pc-button-desk-case.stl, pc-button-relay-case.3mf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]
2026-10-01 remote-pc-power-button v2.0.2 (#1)
    [pc-remote-power-button-cases.3mf]
2026-10-01 remote-pc-power-button v2.0.3 (#2)
2026-10-01 remote-pc-power-button v2.0.4 (#3)

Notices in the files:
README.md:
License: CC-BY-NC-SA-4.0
